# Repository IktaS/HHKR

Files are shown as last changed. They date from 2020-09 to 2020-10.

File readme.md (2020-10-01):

# HHKR

HHKR stands for HHKere, Kere in indonesia means poor. So this is a Poor Man's HHKB PCB, with additional feature such as OLED screen to fill HHKB's empty bottom right space.
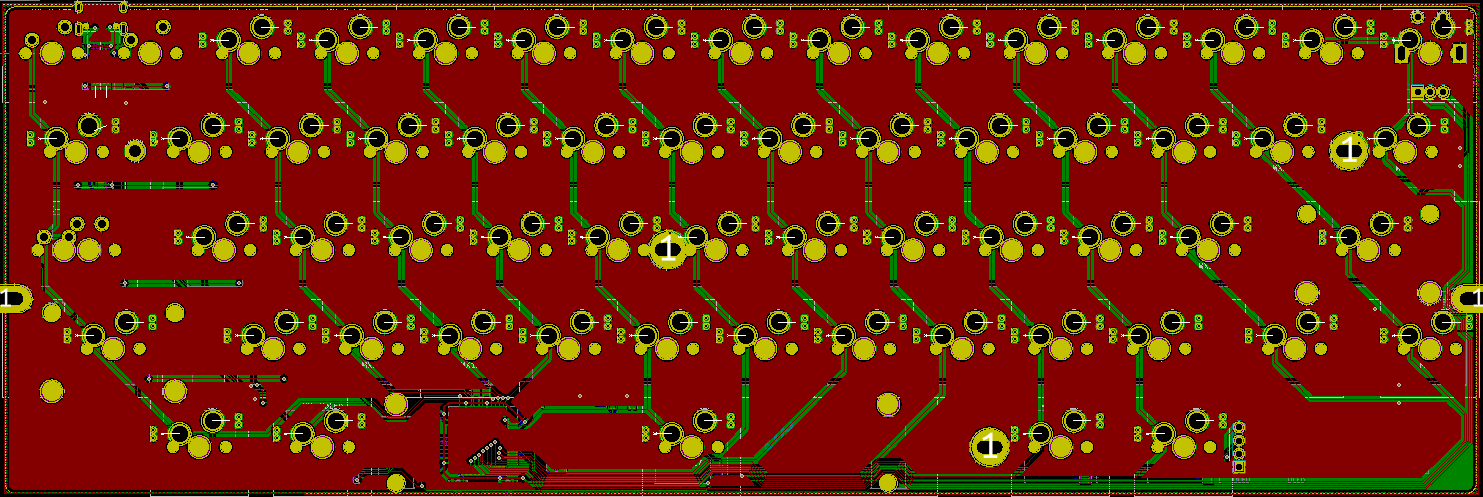
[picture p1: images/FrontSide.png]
Front Side

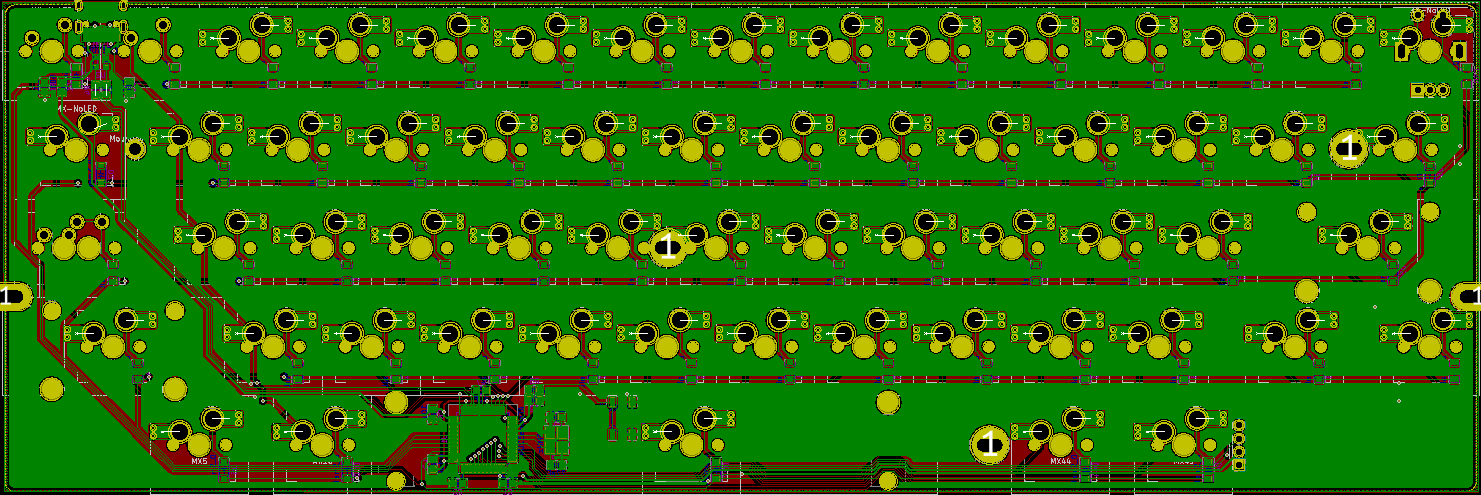
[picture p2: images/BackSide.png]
Back Side

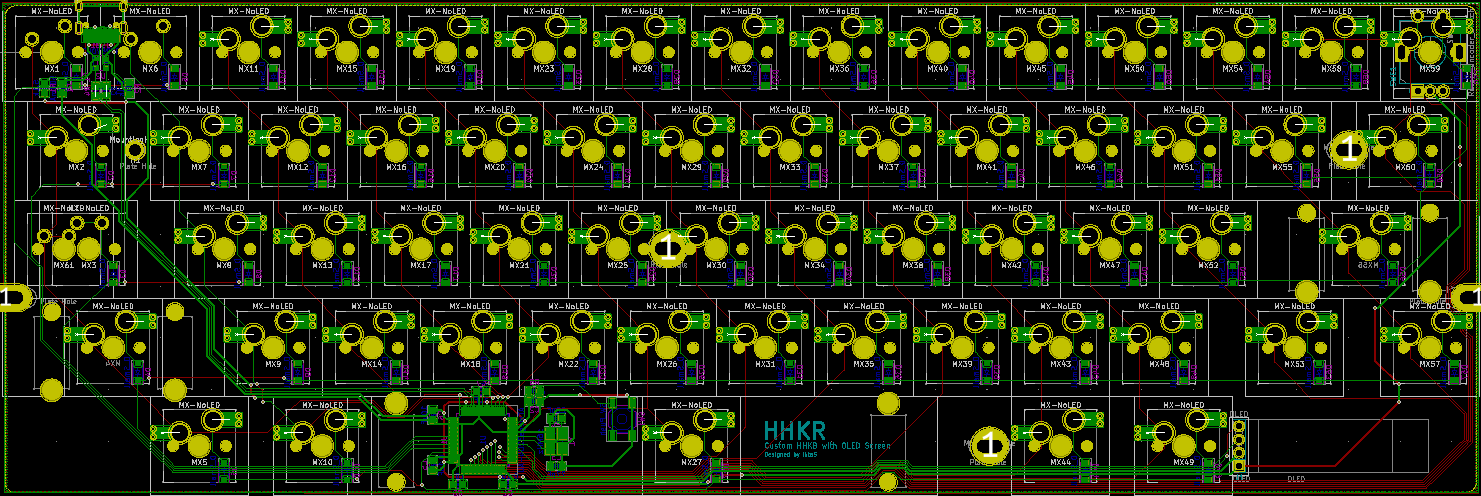
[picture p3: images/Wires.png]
Wires

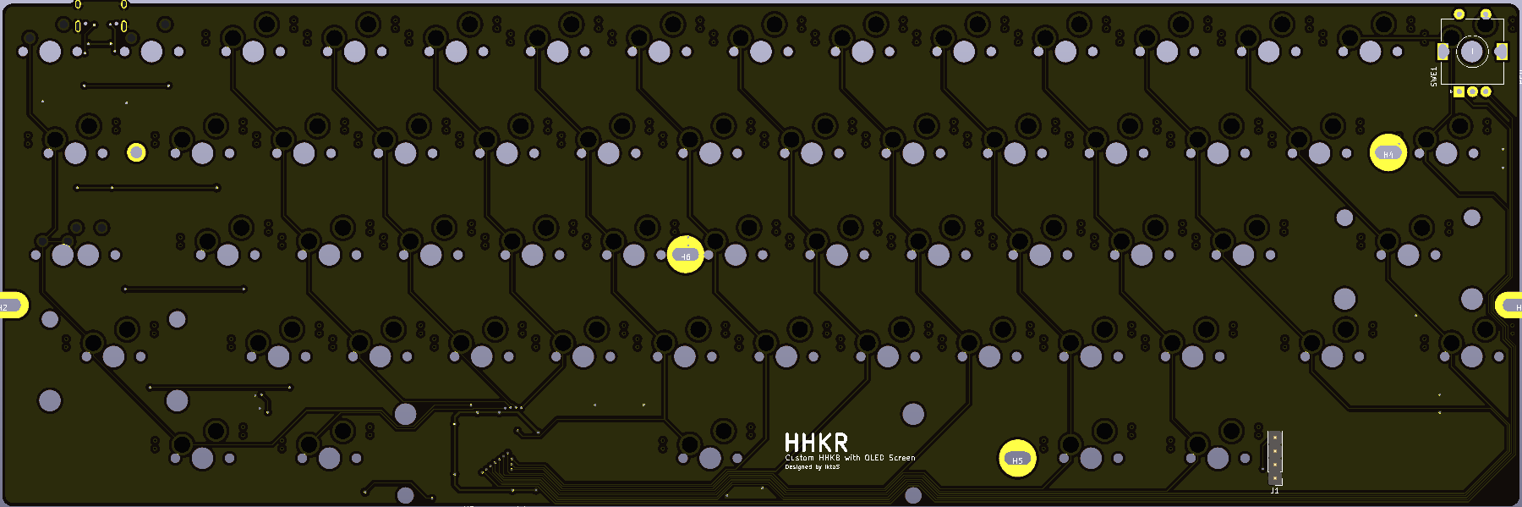
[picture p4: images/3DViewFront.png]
Front Side 3D Front Side 3D View

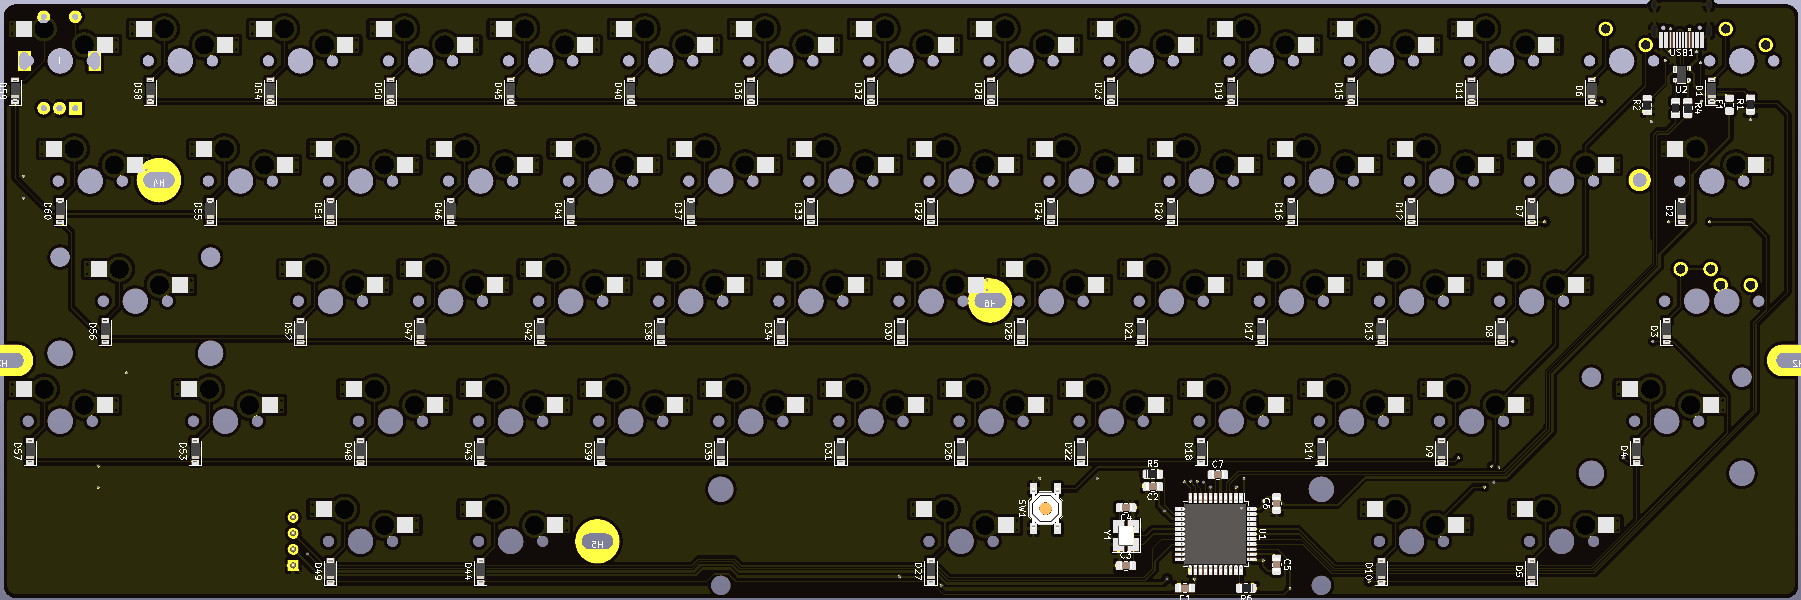
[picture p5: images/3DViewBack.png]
Back Side 3D Back Side 3D View


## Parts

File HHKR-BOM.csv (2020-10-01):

Id | Designator | Package | Quantity | Designation | Supplier and ref
1 | MX60,MX30,MX22,MX18,MX17,MX16,MX59,MX58,MX57,MX55,MX54,MX53,MX52,MX51,MX50,MX49,MX48,MX47,MX46,MX45,MX44,MX43,MX42,MX41,MX40,MX39,MX38,MX37,MX36,MX35,MX34,MX33,MX32,MX31,MX29,MX28,MX26,MX25,MX24,MX23,MX21,MX20,MX19,MX15,MX14,MX13,MX12,MX11,MX10,MX9,MX8,MX7,MX5,MX2 | MXOnly-1U-Hotswap-Antishear | 54 | MX-NoLED
2 | H6,H5,H4 | HoleM2Wide | 3 | MountingHole
3 | H3,H2 | HoleVeryWideM2 | 2 | MountingHole
4 | H1 | Generic-Mounthole | 1 | MountingHole
5 | MX27 | MXOnly-6U-ReversedStabilizers-NoLED-HotSwap-AntiShear | 1 | MX-NoLED
6 | R5,R6 | R_0805_2012Metric_Pad1.15x1.40mm_HandSolder | 2 | 10k
7 | C2,C1,C5 | C_0805_2012Metric_Pad1.15x1.40mm_HandSolder | 3 | 0.1uF
8 | C4,C3 | C_0805_2012Metric_Pad1.15x1.40mm_HandSolder | 2 | 22pF
9 | Y1 | Crystal_SMD_3225-4Pin_3.2x2.5mm_HandSoldering | 1 | 16MHz
10 | SW1 | SW_SPST_TL3342 | 1 | SW_Push
11 | C7 | C_0805_2012Metric_Pad1.15x1.40mm_HandSolder | 1 | 1uF
12 | C6 | C_0805_2012Metric_Pad1.15x1.40mm_HandSolder | 1 | 10uF
13 | R1,R2 | R_0805_2012Metric_Pad1.15x1.40mm_HandSolder | 2 | 5.1k
14 | U2 | SOT143B | 1 | PRTR5V0U2X
15 | F1 | Fuse_0805_2012Metric_Pad1.15x1.40mm_HandSolder | 1 | 500mA
16 | MX61,MX3,MX6,MX1 | MXOnly-1U-NoLED | 4 | MX-NoLED
17 | MX4,MX56 | MXOnly-2.25U-Hotswap-AntiShear | 2 | MX-NoLED
18 | D16,D60,D59,D58,D57,D56,D55,D54,D53,D52,D51,D50,D49,D48,D47,D46,D45,D44,D43,D42,D41,D40,D39,D38,D37,D36,D35,D34,D33,D32,D31,D30,D29,D28,D27,D26,D25,D24,D23,D22,D21,D20,D19,D18,D17,D15,D14,D13,D12,D11,D10,D9,D8,D7,D6,D5,D4,D3,D2,D1 | D_SOD-123-Pretty | 60 | D_Small
19 | USB1 | HRO-TYPE-C-31-M-12-HandSoldering | 1 | HRO-TYPE-C-31-M-12
20 | U1 | TQFP-44_10x10mm_P0.8mm | 1 | ATmega32U4-AU
21 | SWE1 | RotaryEncoder_Alps_EC11E-Switch_Vertical_H20mm | 1 | Rotary_Encoder_Switch
22 | R4,R3 | R_0805_2012Metric_Pad1.15x1.40mm_HandSolder | 2 | 22
23 | J1 | PinHeader_1x04_P2.54mm_Vertical | 1 | OLED

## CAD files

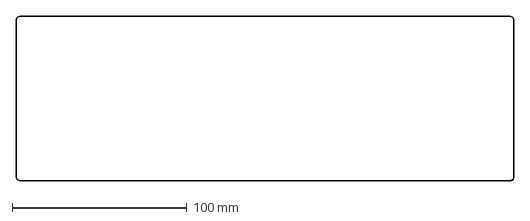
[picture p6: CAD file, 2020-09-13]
PCBReference/EdgeCut.dxf
284.7 x 94.2 mm

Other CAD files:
PCBReference/Reference.dxf
Plate/HHKR-ai-03.dxf
Plate/HHKPill-ai-03.dxf

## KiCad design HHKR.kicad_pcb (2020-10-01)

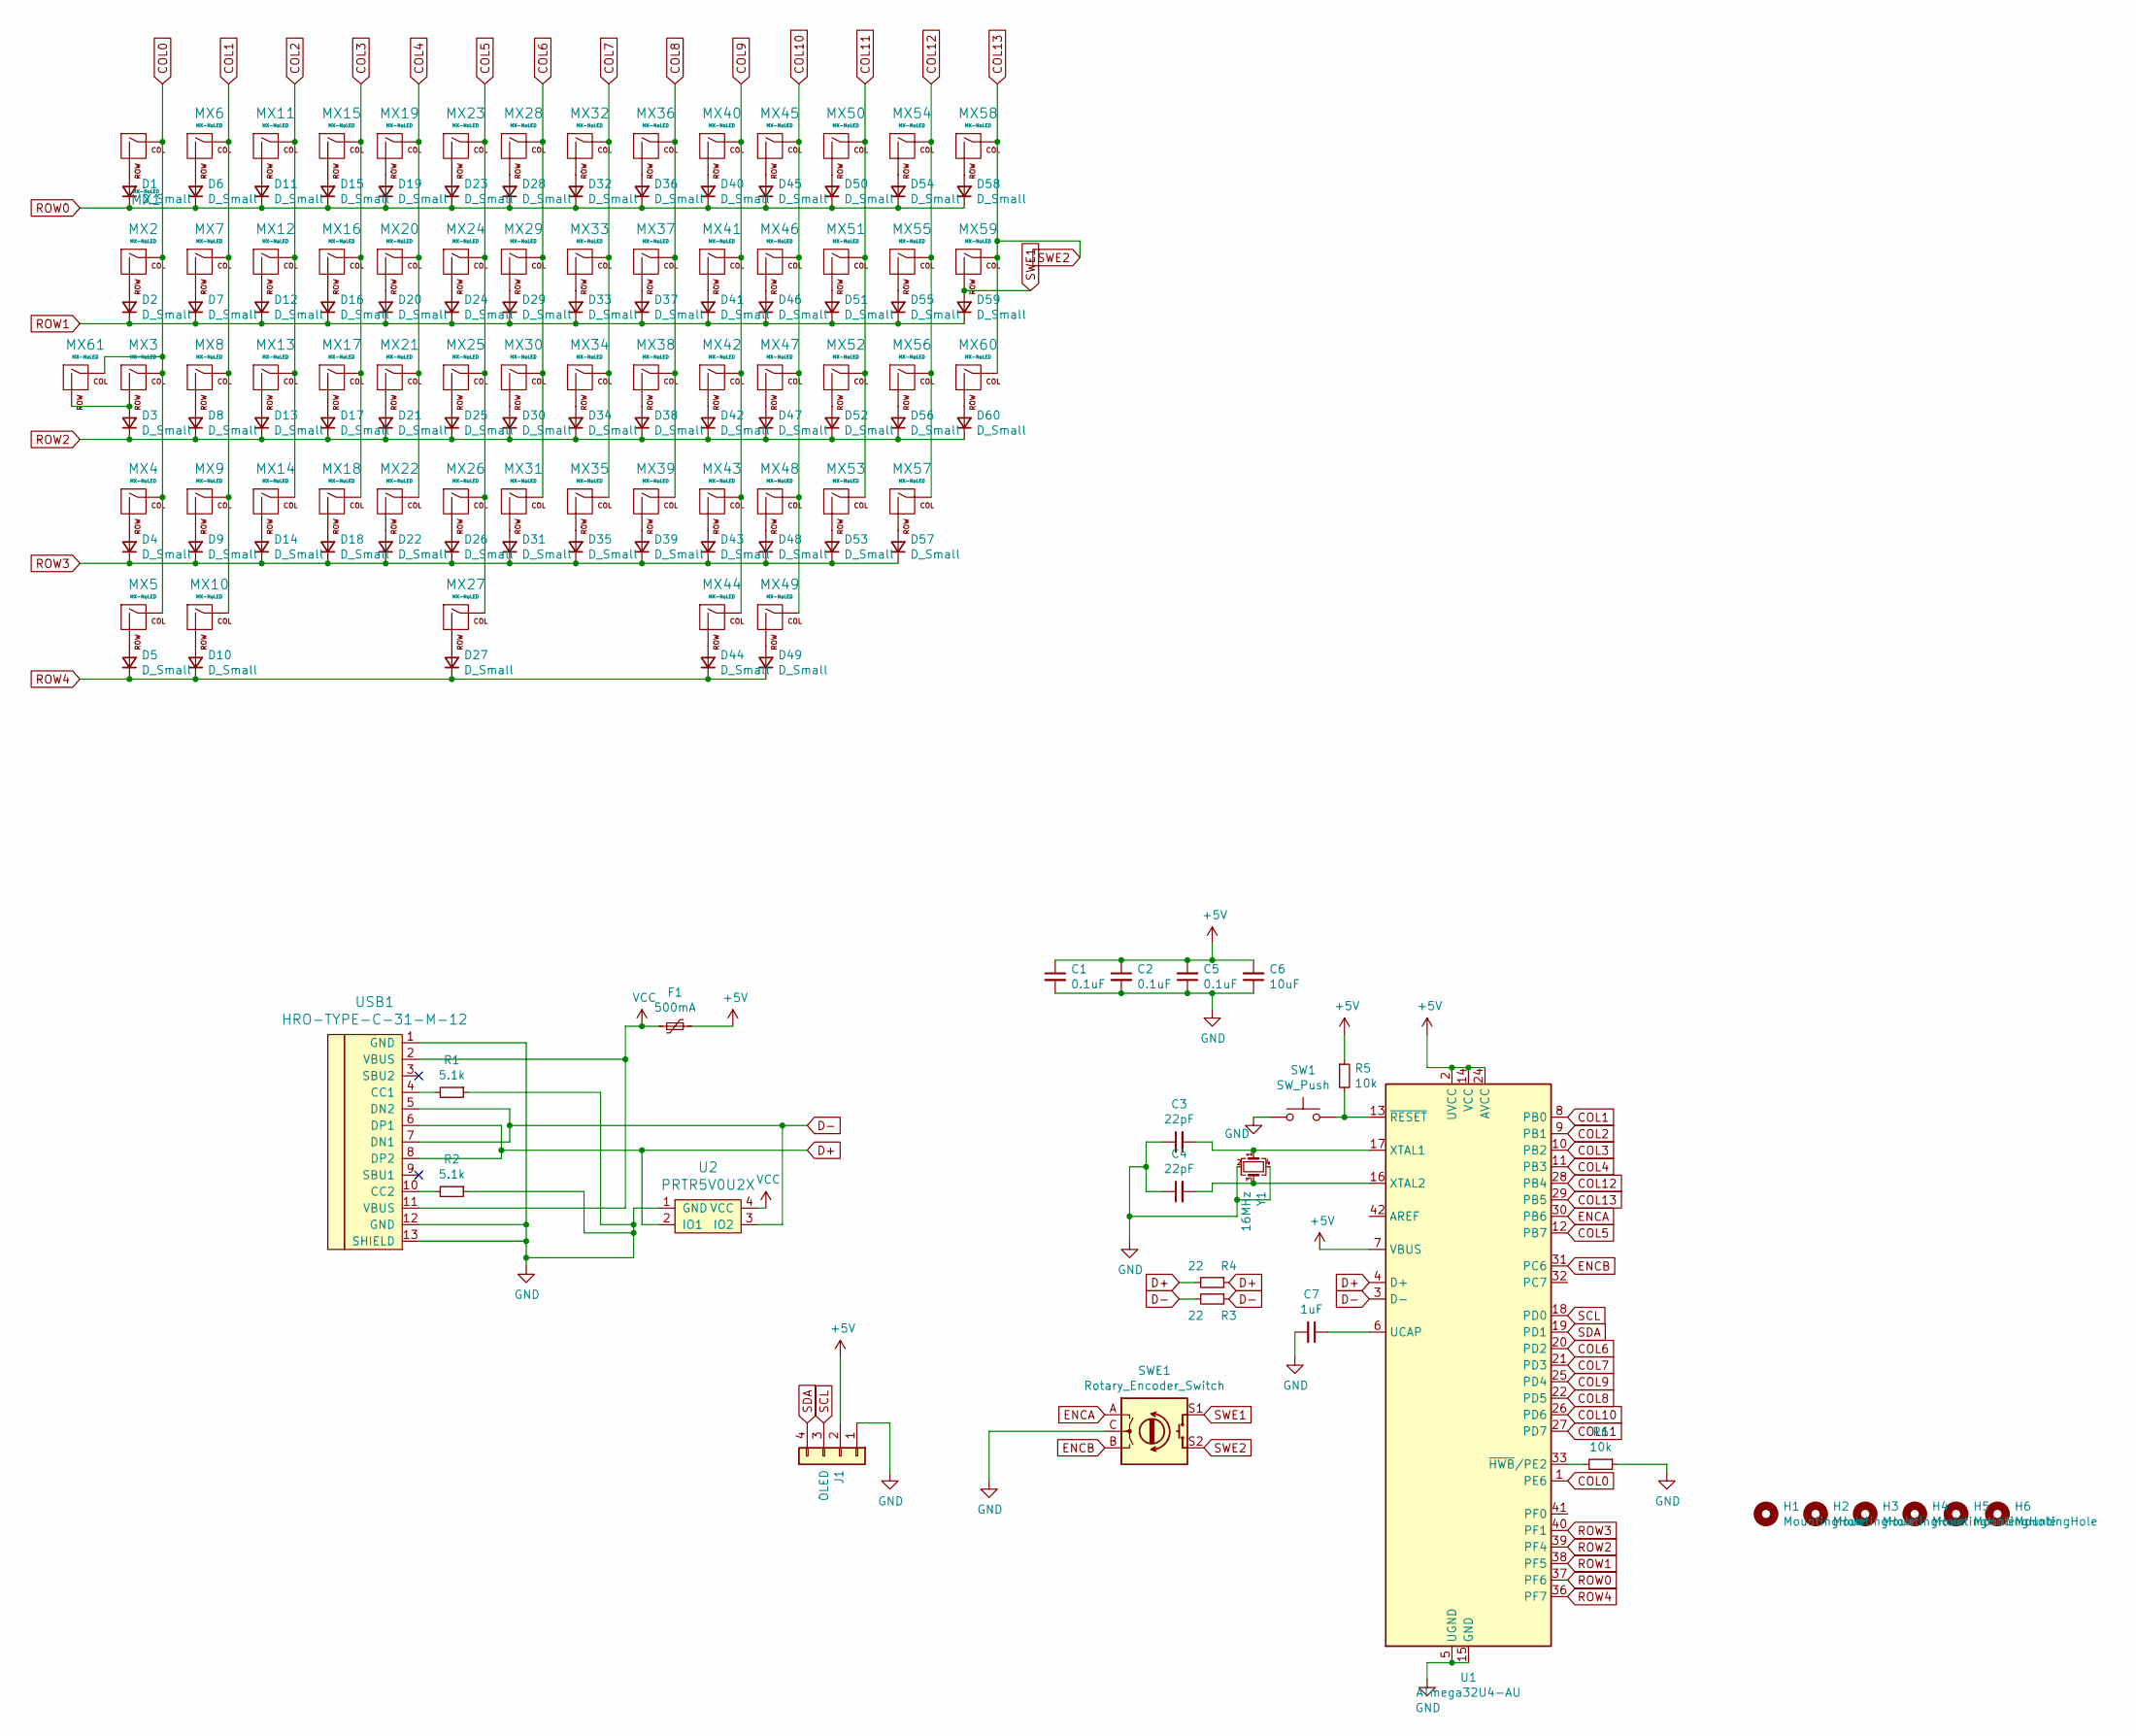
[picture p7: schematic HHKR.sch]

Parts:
C1, C2, C5: 0.1uF; C_0805_2012Metric_Pad1.15x1.40mm_HandSolder
C3, C4: 22pF; C_0805_2012Metric_Pad1.15x1.40mm_HandSolder
C6: 10uF; C_0805_2012Metric_Pad1.15x1.40mm_HandSolder
C7: 1uF; C_0805_2012Metric_Pad1.15x1.40mm_HandSolder
D1, D2, D3, D4, D5, D6, D7, D8, D9, D10, D11, D12, D13, D14, D15, D16, D17, D18, D19, D20, D21, D22, D23, D24, D25, D26, D27, D28, D29, D30, D31, D32, D33, D34, D35, D36, D37, D38, D39, D40, D41, D42, D43, D44, D45, D46, D47, D48, D49, D50, D51, D52, D53, D54, D55, D56, D57, D58, D59, D60: D_Small; D_SOD-123-Pretty
F1: 500mA; Fuse_0805_2012Metric_Pad1.15x1.40mm_HandSolder
H1: MountingHole; Generic-Mounthole
H2, H3: MountingHole; HoleVeryWideM2
H4, H5, H6: MountingHole; HoleM2Wide
J1: OLED; PinHeader_1x04_P2.54mm_Vertical
MX1, MX3, MX6, MX61: MX-NoLED; MXOnly-1U-NoLED
MX2, MX5, MX7, MX8, MX9, MX10, MX11, MX12, MX13, MX14, MX15, MX16, MX17, MX18, MX19, MX20, MX21, MX22, MX23, MX24, MX25, MX26, MX28, MX29, MX30, MX31, MX32, MX33, MX34, MX35, MX36, MX37, MX38, MX39, MX40, MX41, MX42, MX43, MX44, MX45, MX46, MX47, MX48, MX49, MX50, MX51, MX52, MX53, MX54, MX55, MX57, MX58, MX59, MX60: MX-NoLED; MXOnly-1U-Hotswap-Antishear
MX4, MX56: MX-NoLED; MXOnly-2.25U-Hotswap-AntiShear
MX27: MX-NoLED; MXOnly-6U-ReversedStabilizers-NoLED-HotSwap-AntiShear
R1, R2: 5.1k; R_0805_2012Metric_Pad1.15x1.40mm_HandSolder
R3, R4: 22; R_0805_2012Metric_Pad1.15x1.40mm_HandSolder
R5, R6: 10k; R_0805_2012Metric_Pad1.15x1.40mm_HandSolder
SW1: SW_Push; SW_SPST_TL3342
SWE1: Rotary_Encoder_Switch; RotaryEncoder_Alps_EC11E-Switch_Vertical_H20mm
U1: ATmega32U4-AU; TQFP-44_10x10mm_P0.8mm
U2: PRTR5V0U2X; SOT143B
USB1: HRO-TYPE-C-31-M-12; HRO-TYPE-C-31-M-12-HandSoldering
Y1: 16MHz; Crystal_SMD_3225-4Pin_3.2x2.5mm_HandSoldering

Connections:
+5V: C1.1, C2.1, C5.2, C6.2, F1.1, J1.2, R5.1, U1.2 (UVCC), U1.7 (VBUS), U1.14 (VCC), U1.24 (AVCC), U1.34 (VCC), U1.44 (AVCC)
COL0: MX1.1 (COL), MX2.1 (COL), MX3.1 (COL), MX4.1 (COL), MX5.1 (COL), MX61.1 (COL), U1.1 (PE6)
COL1: MX6.1 (COL), MX7.1 (COL), MX8.1 (COL), MX9.1 (COL), MX10.1 (COL), U1.8 (PB0)
COL2: MX11.1 (COL), MX12.1 (COL), MX13.1 (COL), MX14.1 (COL), U1.9 (PB1)
COL3: MX15.1 (COL), MX16.1 (COL), MX17.1 (COL), MX18.1 (COL), U1.10 (PB2)
COL4: MX19.1 (COL), MX20.1 (COL), MX21.1 (COL), MX22.1 (COL), U1.11 (PB3)
COL5: MX23.1 (COL), MX24.1 (COL), MX25.1 (COL), MX26.1 (COL), MX27.1 (COL), U1.12 (PB7)
COL6: MX28.1 (COL), MX29.1 (COL), MX30.1 (COL), MX31.1 (COL), U1.20 (PD2)
COL7: MX32.1 (COL), MX33.1 (COL), MX34.1 (COL), MX35.1 (COL), U1.21 (PD3)
COL8: MX36.1 (COL), MX37.1 (COL), MX38.1 (COL), MX39.1 (COL), U1.22 (PD5)
COL9: MX40.1 (COL), MX41.1 (COL), MX42.1 (COL), MX43.1 (COL), MX44.1 (COL), U1.25 (PD4)
COL10: MX45.1 (COL), MX46.1 (COL), MX47.1 (COL), MX48.1 (COL), MX49.1 (COL), U1.26 (PD6)
COL11: MX50.1 (COL), MX51.1 (COL), MX52.1 (COL), MX53.1 (COL), U1.27 (PD7)
COL12: MX54.1 (COL), MX55.1 (COL), MX56.1 (COL), MX57.1 (COL), U1.28 (PB4)
COL13: MX58.1 (COL), MX59.1 (COL), MX60.1 (COL), SWE1.S2, U1.29 (PB5)
D+: R3.1, R3.2, U1.4 (D+), U2.2 (IO1), USB1.6 (DP1), USB1.8 (DP2)
D-: R4.1, R4.2, U1.3 (D-), U2.3 (IO2), USB1.5 (DN2), USB1.7 (DN1)
ENCA: SWE1.A, U1.30 (PB6)
ENCB: SWE1.B, U1.31 (PC6)
GND: C1.2, C2.2, C3.1, C4.1, C5.1, C6.1, C7.2, J1.1, R1.1, R2.1, R6.1, SW1.1, SWE1.C, U1.5 (UGND), U1.15 (GND), U1.23 (GND), U1.35 (GND), U1.43 (GND), U2.1 (GND), USB1.1 (GND), USB1.12 (GND), USB1.13 (SHIELD), Y1.2, Y1.4
unnamed: C3.2, U1.17 (XTAL1), Y1.1
unnamed: C4.2, U1.16 (XTAL2), Y1.3
unnamed: C7.1, U1.6 (UCAP)
unnamed: D1.2 (A), MX1.2 (ROW)
unnamed: D2.2 (A), MX2.2 (ROW)
unnamed: D3.2 (A), MX3.2 (ROW), MX61.2 (ROW)
unnamed: D4.2 (A), MX4.2 (ROW)
unnamed: D5.2 (A), MX5.2 (ROW)
unnamed: D6.2 (A), MX6.2 (ROW)
unnamed: D7.2 (A), MX7.2 (ROW)
unnamed: D8.2 (A), MX8.2 (ROW)
unnamed: D9.2 (A), MX9.2 (ROW)
unnamed: D10.2 (A), MX10.2 (ROW)
unnamed: D11.2 (A), MX11.2 (ROW)
unnamed: D12.2 (A), MX12.2 (ROW)
unnamed: D13.2 (A), MX13.2 (ROW)
unnamed: D14.2 (A), MX14.2 (ROW)
unnamed: D15.2 (A), MX15.2 (ROW)
unnamed: D16.2 (A), MX16.2 (ROW)
unnamed: D17.2 (A), MX17.2 (ROW)
unnamed: D18.2 (A), MX18.2 (ROW)
unnamed: D19.2 (A), MX19.2 (ROW)
unnamed: D20.2 (A), MX20.2 (ROW)
unnamed: D21.2 (A), MX21.2 (ROW)
unnamed: D22.2 (A), MX22.2 (ROW)
unnamed: D23.2 (A), MX23.2 (ROW)
unnamed: D24.2 (A), MX24.2 (ROW)
unnamed: D25.2 (A), MX25.2 (ROW)
unnamed: D26.2 (A), MX26.2 (ROW)
unnamed: D27.2 (A), MX27.2 (ROW)
unnamed: D28.2 (A), MX28.2 (ROW)
unnamed: D29.2 (A), MX29.2 (ROW)
unnamed: D30.2 (A), MX30.2 (ROW)
unnamed: D31.2 (A), MX31.2 (ROW)
unnamed: D32.2 (A), MX32.2 (ROW)
unnamed: D33.2 (A), MX33.2 (ROW)
unnamed: D34.2 (A), MX34.2 (ROW)
unnamed: D35.2 (A), MX35.2 (ROW)
unnamed: D36.2 (A), MX36.2 (ROW)
unnamed: D37.2 (A), MX37.2 (ROW)
unnamed: D38.2 (A), MX38.2 (ROW)
unnamed: D39.2 (A), MX39.2 (ROW)
unnamed: D40.2 (A), MX40.2 (ROW)
unnamed: D41.2 (A), MX41.2 (ROW)
unnamed: D42.2 (A), MX42.2 (ROW)
unnamed: D43.2 (A), MX43.2 (ROW)
unnamed: D44.2 (A), MX44.2 (ROW)
unnamed: D45.2 (A), MX45.2 (ROW)
unnamed: D46.2 (A), MX46.2 (ROW)
unnamed: D47.2 (A), MX47.2 (ROW)
unnamed: D48.2 (A), MX48.2 (ROW)
unnamed: D49.2 (A), MX49.2 (ROW)
unnamed: D50.2 (A), MX50.2 (ROW)
unnamed: D51.2 (A), MX51.2 (ROW)
unnamed: D52.2 (A), MX52.2 (ROW)
unnamed: D53.2 (A), MX53.2 (ROW)
unnamed: D54.2 (A), MX54.2 (ROW)
unnamed: D55.2 (A), MX55.2 (ROW)
unnamed: D56.2 (A), MX56.2 (ROW)
unnamed: D57.2 (A), MX57.2 (ROW)
unnamed: D58.2 (A), MX58.2 (ROW)
unnamed: D60.2 (A), MX60.2 (ROW)
unnamed: R1.2, USB1.4 (CC1)
unnamed: R2.2, USB1.10 (CC2)
unnamed: R5.2, SW1.2, U1.13 (~RESET)
unnamed: R6.2, U1.33 (~HWB~/PE2)
ROW0: D1.1 (K), D6.1 (K), D11.1 (K), D15.1 (K), D19.1 (K), D23.1 (K), D28.1 (K), D32.1 (K), D36.1 (K), D40.1 (K), D45.1 (K), D50.1 (K), D54.1 (K), D58.1 (K), U1.37 (PF6)
ROW1: D2.1 (K), D7.1 (K), D12.1 (K), D16.1 (K), D20.1 (K), D24.1 (K), D29.1 (K), D33.1 (K), D37.1 (K), D41.1 (K), D46.1 (K), D51.1 (K), D55.1 (K), D59.1 (K), U1.38 (PF5)
ROW2: D3.1 (K), D8.1 (K), D13.1 (K), D17.1 (K), D21.1 (K), D25.1 (K), D30.1 (K), D34.1 (K), D38.1 (K), D42.1 (K), D47.1 (K), D52.1 (K), D56.1 (K), D60.1 (K), U1.39 (PF4)
ROW3: D4.1 (K), D9.1 (K), D14.1 (K), D18.1 (K), D22.1 (K), D26.1 (K), D31.1 (K), D35.1 (K), D39.1 (K), D43.1 (K), D48.1 (K), D53.1 (K), D57.1 (K), U1.40 (PF1)
ROW4: D5.1 (K), D10.1 (K), D27.1 (K), D44.1 (K), D49.1 (K), U1.36 (PF7)
SCL: J1.3, U1.18 (PD0)
SDA: J1.4, U1.19 (PD1)
SWE1: D59.2 (A), MX59.2 (ROW), SWE1.S1
VCC: F1.2, U2.4 (VCC), USB1.2 (VBUS), USB1.11 (VBUS)

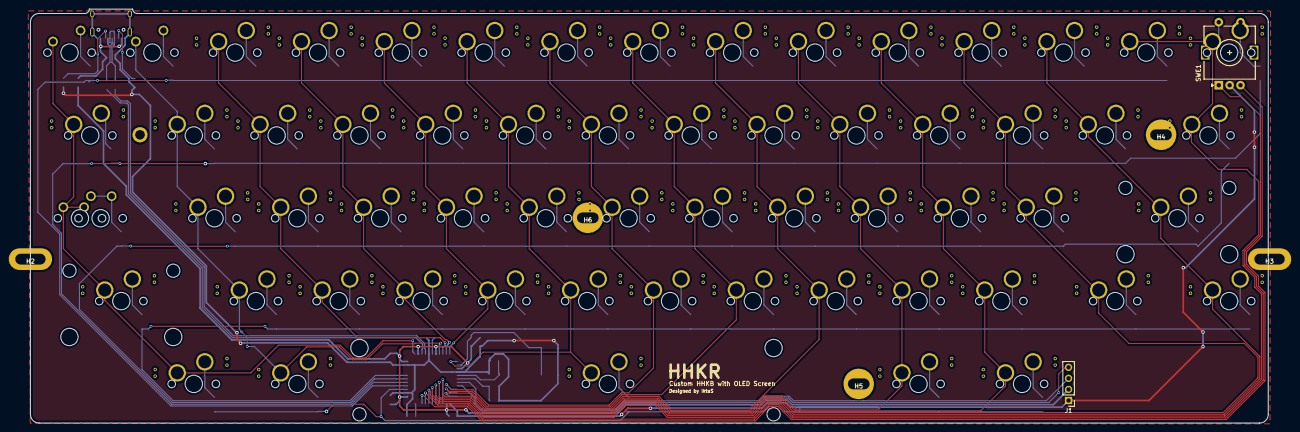
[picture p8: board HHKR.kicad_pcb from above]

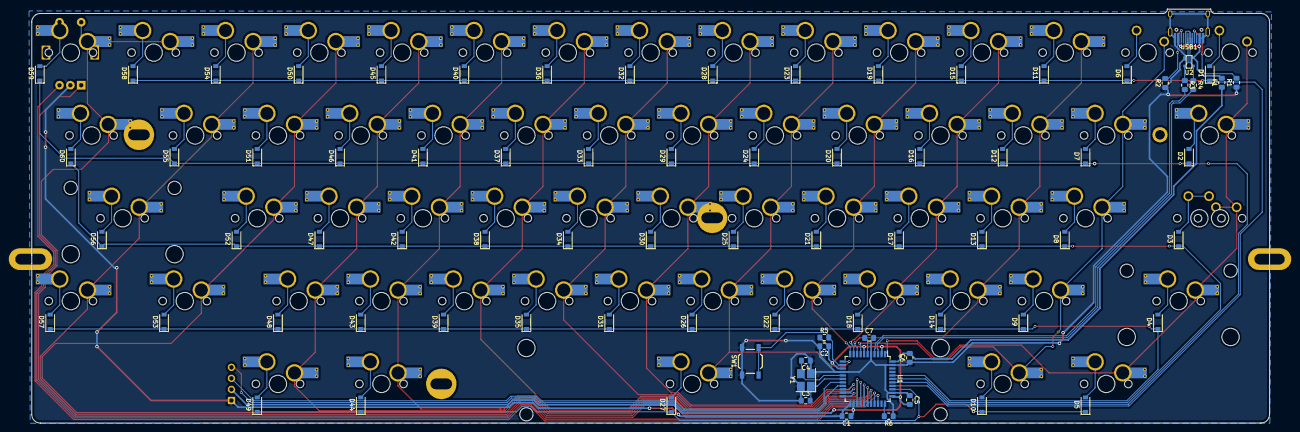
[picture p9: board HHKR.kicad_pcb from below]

Board: 2 copper layers, 284.7 x 95.2 mm, 148 parts (79 on the bottom side), 95 nets.
